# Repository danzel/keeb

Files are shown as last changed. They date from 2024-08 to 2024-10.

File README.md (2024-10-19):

# References

Nice ergogen:
https://ergogen.ceoloide.com/

General everything:
https://github.com/soundmonster/samoklava

Has a 3d print case:
https://github.com/rwalkr/eskarp

Measurements:
[Choc Switch](https://github.com/keyboardio/keyswitch_documentation/blob/master/datasheets/Kailh/CPG135001D01.pdf)
[Raspberry Pi Pico, page 6](https://datasheets.raspberrypi.com/pico/pico-datasheet.pdf)

# Print settings:

100% infill
0.2 layer height

Print 4x of `clip`

# miryoku build

https://github.com/danzel/miryoku_qmk/actions/workflows/build-danzel-keeb.yml
Run workflow

# Parts

https://keebd.com/en-nz/products/6x6x4-3mm-dip-push-button-switch
https://keebd.com/products/24cm-dual-90-degree-nylon-3-5mm-to-3-5mm-male-trrs-cable
https://keebd.com/products/trrs-3-5mm-female-jack-pj-320a
https://keebd.com/products/helios-controller
https://keebd.com/products/ambients-silent-linear-twilight-choc-switches

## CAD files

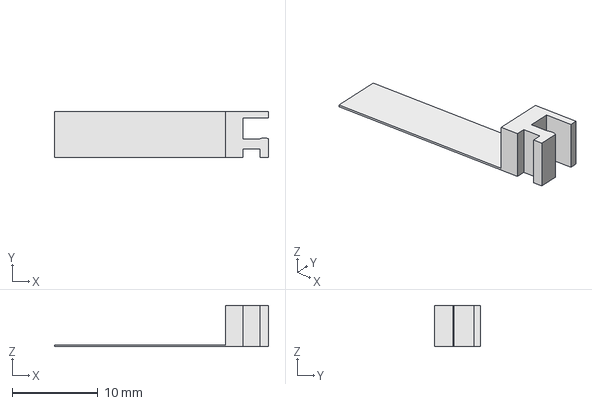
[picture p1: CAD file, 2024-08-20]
clip.FCStd
25.0 x 5.40 x 4.80 mm

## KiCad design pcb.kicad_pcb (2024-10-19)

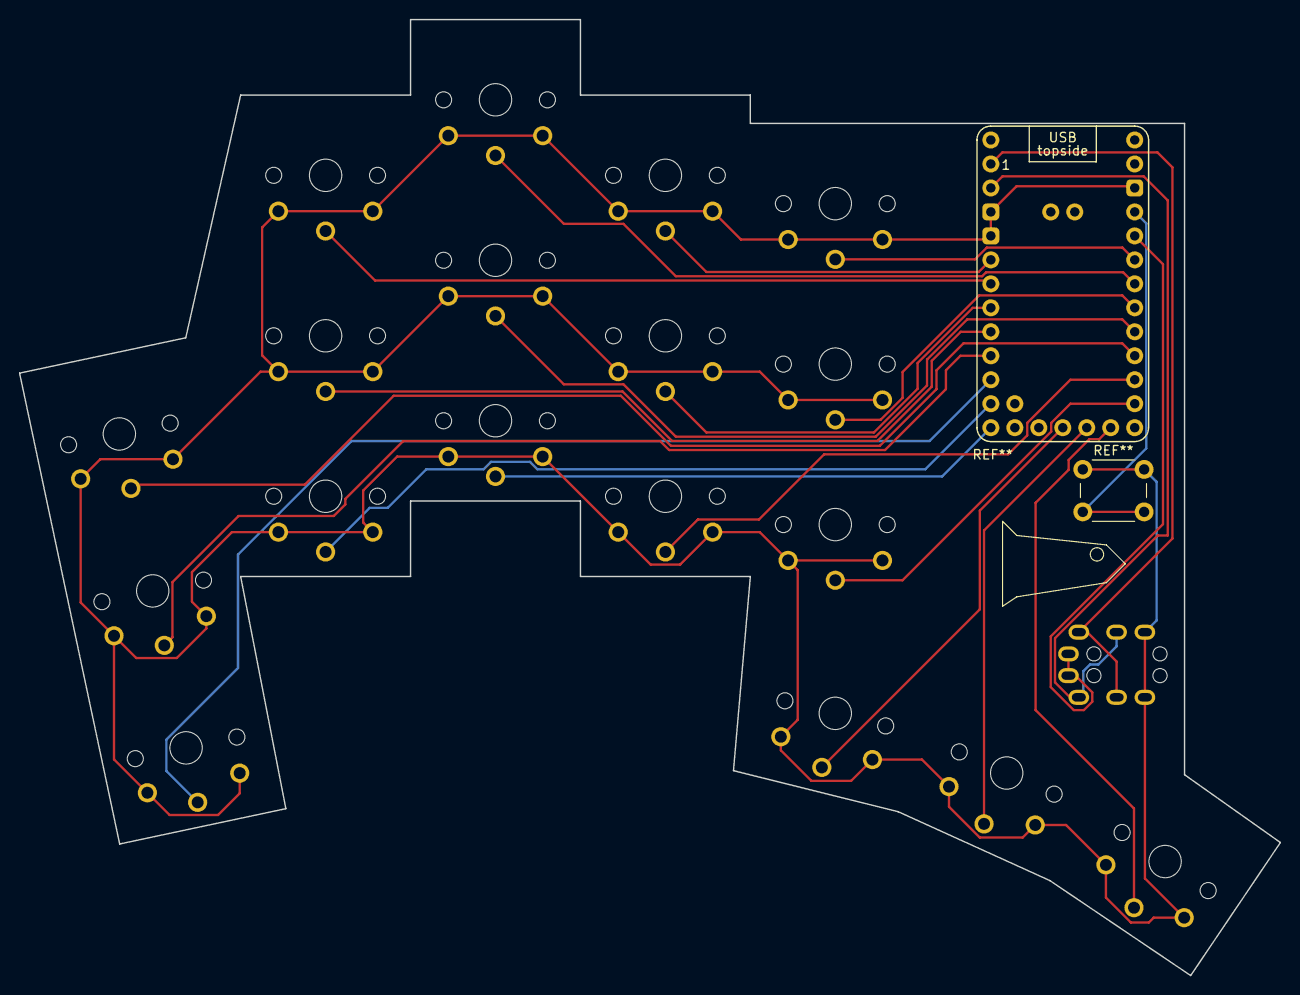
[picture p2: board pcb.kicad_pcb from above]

Board: 2 copper layers, 133.6 x 101.3 mm, 19 parts (0 on the bottom side), 2 nets.

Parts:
S1, S2, S3, S4, S5, S6, S7, S8, S9, S10, S11, S12, S13, S14, S15, S16, S17, S18: PG1350
TRRS1: TRRS-PJ-320A-dual

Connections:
GND: S1.1, S2.1, S3.1, S4.1, S5.1, S6.1, S7.1, S8.1, S9.1, S10.1, S11.1, S12.1, S13.1, S14.1, S15.1, S16.1, S17.1, S18.1, TRRS1.4
P0: TRRS1.2, TRRS1.3
P1: TRRS1.2, TRRS1.3

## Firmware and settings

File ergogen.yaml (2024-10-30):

units:
  # Proxy Spacing Variables (choc)
  kx: cx
  ky: cy
  # Default visuals look like choc
  $default_width: cx
  $default_height: cy
  # choc switch Variables
  # ref https://github.com/josefadamcik/SofleKeyboard/issues/136#issuecomment-1043234757
  choc_grip_thickness: 1.2 # 1.3, but 1.2 seems perfect?
  choc_thick_thickness: 2.2 # From top of grip area to bottom flat area (above the legs)
  choc_leg_thickness: 2.65
  #choc variables from PCB recommendations
  #https://github.com/keyboardio/keyswitch_documentation/blob/master/datasheets/Kailh/CPG135001D01.pdf
  #the bottom image with "PCB" written under it
  choc_center_leg_diameter: 3.4
  choc_side_leg_diameter: 1.9
  choc_side_leg_x_offset: 5.5
  choc_pin_diameter: 1.2
  choc_center_pin_y_offset: 5.9
  choc_side_pin_y_offset: 3.8
  choc_side_pin_x_offset: 5.0
  # How far to pad out the plate from keycap edges. Walls go around this
  px: kx + 0
  py: ky + 0

  pcb_thickness: 1.6
  hole_thickness: 1.4
  #How thick the bottom "layer" is, this layer is never cut
  bottom_thickness: 0.4


  pcb_padding: 0.1
  #Wall around outside of case
  wall_width: 2
  #on top of the pcb
  wall_thickness: 1

  # Micro Variables
  micro_x: 6
  micro_w: 18
  micro_h: 33
  #reset button
  reset_x: 16
  reset_y: 35
  reset_w: 9
  reset_h: 7

  trrs_x: 15
  trrs_y: 53
  trrs_w: 14
  trrs_h: 9


  # Individual finger Variables
  thumbsplay: -10
  pinkysplay: 12
points:
  zones:
    matrix:
      key:
        padding: 1ky
        spread: 1kx
      columns:
        pinky:
          key.splay: pinkysplay
        ring:
          key.stagger: 23
          key.splay: -pinkysplay
          key.spread: kx + 2
        middle:
          key.stagger: 8
        index:
          key.stagger: -8
        inner:
          key.stagger: -3
      rows:
        bottom:
        home:
        top:
    thumbfan:
      anchor:
        ref: matrix_inner_bottom
        shift: [0, -20]
      columns:
        near:
          key.splay: thumbsplay - 4
        home:
          key.spread: 18.25
          key.splay: thumbsplay
          key.origin: [-9.5, -6]
        far:
          key.spread: 18.25
          key.splay: thumbsplay
          key.origin: [-9.5, -6]
      rows:
        thumb:
outlines:
  keycaps:
  # Just for testing
  - what: rectangle
    where: true
    size: [kx, ky]
    corner: 1
  border:
    # Trace around the outside of the keys
    - what: polygon
      operation: stack
      points:
        - ref: matrix_pinky_top
          shift: [-.5px, .5py]
        - ref: matrix_pinky_top
          shift: [.5px, .5py]
        - ref: matrix_ring_top
          shift: [-.5px, .5py]
        - ref: matrix_ring_top
          shift: [.5px, .5py]
        - ref: matrix_middle_top
          shift: [-.5px, .5py]
        - ref: matrix_middle_top
          shift: [.5px, .5py]
        - ref: matrix_index_top
          shift: [-.5px, .5py]
        - ref: matrix_index_top
          shift: [.5px, .5py]
        - ref: matrix_inner_top
          shift: [-.5px, .5py]
        - ref: matrix_inner_top
          shift: [.5px, .5py]
        # Add space for the pi pico (Disable these two and enable the one after for testplate)
        - ref: matrix_inner_top
          shift: [.5px + 21 + 7, .5py]
        - ref: matrix_inner_top
          shift: [.5px + 21 + 7, .5py - 51 - 18]
        # End of space, start of fixup if it is off
        #- ref: matrix_inner_bottom
        #  shift: [.5px, -.5py]
        # Endof fixup
        - ref: thumbfan_far_thumb
          shift: [.5px, .5py]
        - ref: thumbfan_far_thumb
          shift: [.5px, -.5py]
        - ref: thumbfan_far_thumb
          shift: [-.5px, -.5py]
        - ref: thumbfan_near_thumb
          shift: [.5px, -.5py]
        - ref: thumbfan_near_thumb
          shift: [-.5px, -.5py]
        - ref: matrix_index_bottom
          shift: [.5px, -.5py]
        - ref: matrix_index_bottom
          shift: [-.5px, -.5py]
        - ref: matrix_middle_bottom
          shift: [.5px, -.5py]
        - ref: matrix_middle_bottom
          shift: [-.5px, -.5py]
        - ref: matrix_ring_bottom
          shift: [.5px, -.5py]
        - ref: matrix_ring_bottom
          shift: [-.5px, -.5py]
        - ref: matrix_pinky_bottom
          shift: [.5px, -.5py]
        - ref: matrix_pinky_bottom
          shift: [-.5px, -.5py]
  _border_pcb_padded:
    - what: outline
      name: border
      expand: pcb_padding
  _border_plus_wall:
    - what: outline
      name: border
      expand: wall_width
  holes:
    #holes that the switches fit through
    - what: rectangle
      where: true
      size: [13.8, 13.8]
  header_pin_area:
    #Area around the micro that is thinner than the rest of the plate to give room for header pins
    - what: rectangle
      size: [micro_w, micro_h]
      adjust:
        ref: matrix_inner_top
        shift: [.5px + micro_x + sx / 2, .5py - .1 - sy/2]
    #Under reset button
    - what: rectangle
      size: [reset_w, reset_h]
      adjust:
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

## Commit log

2024-07-23 middle -2mm
2024-07-23 Make the plate thicker around the switches
    Where the clips attach is still thin, but the rest of the plate is the same thickness as the switches from the top of the plate to the bottom flat surface of the switch (before the legs)
2024-07-25 Mounting legs for pico
2024-07-25 Add walls
    The pico legs are too long, will have to make holes in the case for the button and usb to come through
    [ergogen.yaml]
2024-07-26 Add holes for the pico usb and reset to pop through the case
    [ergogen.yaml]
2024-07-26 Fix usb hole size
    [ergogen.yaml]
2024-07-26 Hole for link cable, it can't be as big as it needs to be, might need a resize later
2024-07-26 holes for clips
2024-07-26 Clip model
    [clip.FCStd]
2024-07-27 More space beside pico on outside
2024-07-27 Move pico down a bit, it didn't fit as there are tabs at the end of the pcb that aren't in the spec
    [ergogen.yaml]
2024-07-27 USB hole a tiny bit bigger
2024-07-27 Duplicate the reset hole for both sides
    [ergogen.yaml]
2024-07-27 Holes in base for pico mounts are a bit wider, it didn't fit when printed with same size
    [ergogen.yaml]
2024-07-27 Make the area above the pico thinner and move it up in that direction so there is more room for wiring
2024-07-27 Update clip for new sizing
    [clip.FCStd]
2024-07-28 Cut usb through the inset wall or it gets in the way when mounting
2024-07-28 Make pico poles smaller so they aren't too tight, slightly more room in their matching piece too
    [ergogen.yaml]
2024-07-28 Tweaked the clip a bit, it fits on now
    [clip.FCStd]
2024-07-28 Cut the hollow edges, case edge now follows keys instead of the angled bits
    Trying to reduce empty internal volume to reduce noise maybe
    [ergogen.yaml]
2024-07-28 Thicker wall
    [clip.FCStd]
2024-07-29 Add poles around the keys to hold the plate and base together sort of
2024-07-30 Big redo for a thicker base + misc fixes
    Make the base thicker and put holes for the pins, leaves less room for wiring but hopefully still enough. Hoping that this will reduce the noise when tapping keys.
    Cut a box so you can plug in a usb plug.
    [clip.FCStd]
2024-08-01 Bigger hole for the link cable to fit the cable I'll try use
2024-08-08 Replace link cable hole with a jumper block
    It is quite close to the rpi, might be nice to make the rpi area of the case wider by 1cm
    [ergogen.yaml]
2024-08-08 Move the jumper header next to the wall to give slightly more room for wiring
2024-08-08 Swap the jumper and bottom clip positions
    [ergogen.yaml]
2024-08-20 Slightly thinner bottom of clip, lets it go in without any bulge out
    [clip.FCStd]
2024-10-16 Start on PCB
2024-10-19 Routed PCB, ergogen has wrong nets
    [pcb.kicad_pcb]
2024-10-30 First go at a base, it's a bit tight no the pcb
    [ergogen.yaml]
2024-10-30 Case as printed
